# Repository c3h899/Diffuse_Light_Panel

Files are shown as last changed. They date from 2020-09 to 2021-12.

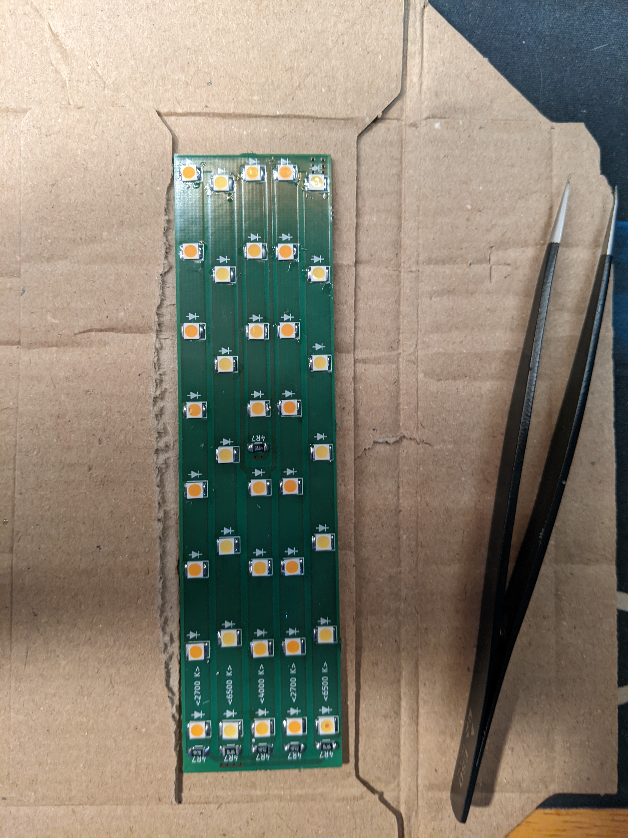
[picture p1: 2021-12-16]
Tri-Color LED/Preview/Proto-Module [Assembled].jpg

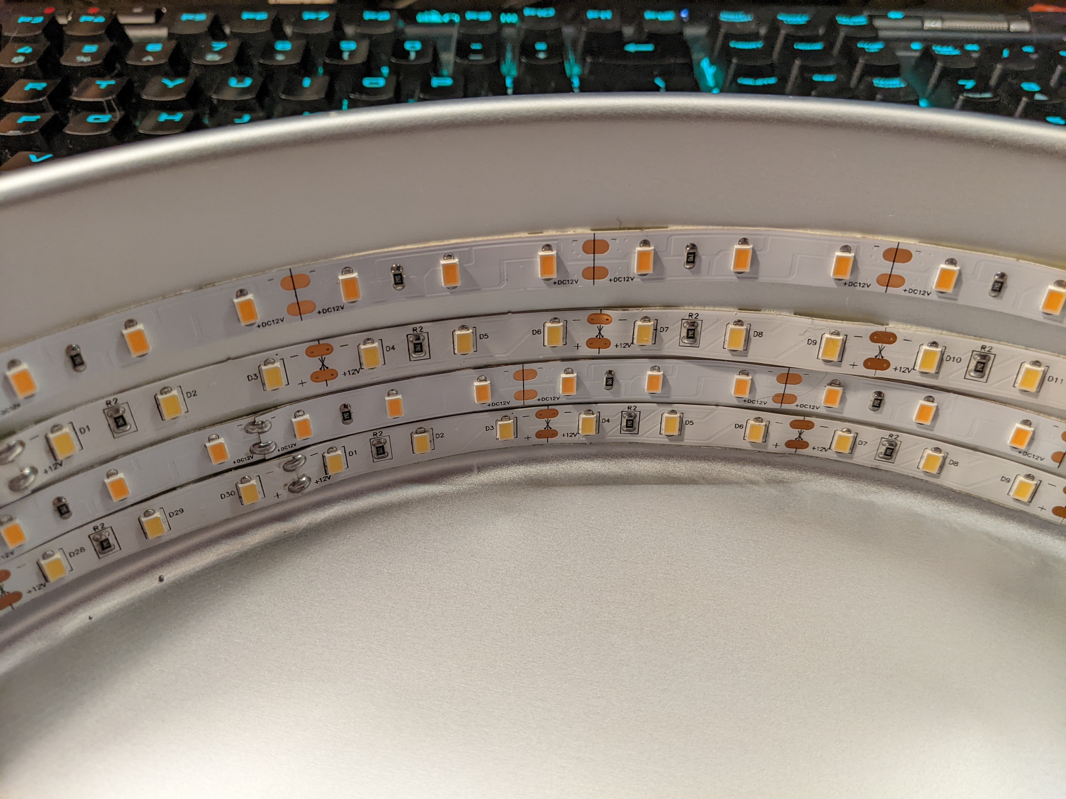
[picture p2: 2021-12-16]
Photos/Revision3_Interrior.jpg

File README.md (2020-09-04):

# Diffuse_Light_Panel
 - This is a derivative work. See LICENSE.

## Principle Design
 - Design is a direct variation on '$40 DIY Cake pan light'. See LICENSE.
 - Rim the interior of a metallic container with 5-ft lengths of LED strip lights.
 - Use two LED strips: 1) warm color temperature, 2) cool color temperature.
 - Use 2-channels of dimming to allow for variable color temperature.
 - Cover the aperture with 2 layers of diffusion material.
 - Result will consume 10-ft total length of LED strip lighting.

## Future Revisions
 - Future implementations should consider these changes for an improved product.
 - Dimmers use 10k (Ohm) multi-turn potentiometer. Depopulate and replace.
 - An externally mounted pair of potentiometers would improve the quality of life.
 - Affix a standard barrel jack to power the lights rather than direct soldering.
 - Power button / switch (12 V, (4 to 6) A minimum rating). 

## Revision 3
 - Built revision 2 in a aluminum, 12-inch circular cake pan.
 - Absence of sharp corners improved ease of applying the LED strips.
 - Recessing the LED strips as deeply as possible is encouraged.
 - Recessing the strips improves lighting uniformity (as one should expect).

## Revision 2
 - Applied 2 layers of the specified diffusion material.
 - SUBSTANTIAL improvement of lighting uniformity. Highly recommended.

## Revision 1
 - Moved to a switch-mode (more-or-less) constant current dimmer.
 - Dimmer requires many turns required before noticeable dimming.
 - Screw terminals on dimmer ineffective. Soldered wires directly to pads.
 - Scan-line artifacts resolved / not noticeable.
 - Moved to a cardboard box lined with printer paper: Acceptable.

## Revision 0
 - Non-Stick bread pan used as container. Aperture: acceptable, AVOID NON-STICK CONTAINERS.
 - (Cheap) PWM Dimmer was used, renders the light incompatible with videography.
 - Scan-line artifacts emerge from the interaction of the PWM and the image sensor.
 - Without dimmer, 2 strips of LEDs draw a (combined) (4 to 5) A at 12 V, (50 to 60) W.
 - At full power, these LEDs get HOT. Intended brightness achieved near 1 A combined.

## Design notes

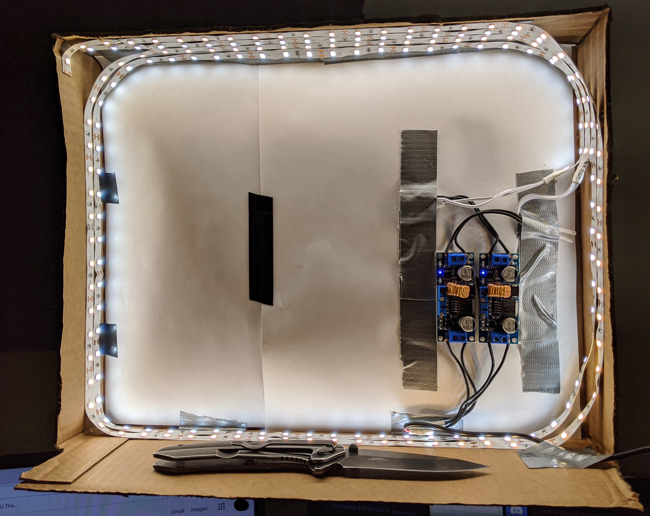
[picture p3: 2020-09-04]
Photos/Revision2_UnEnclosed.jpg

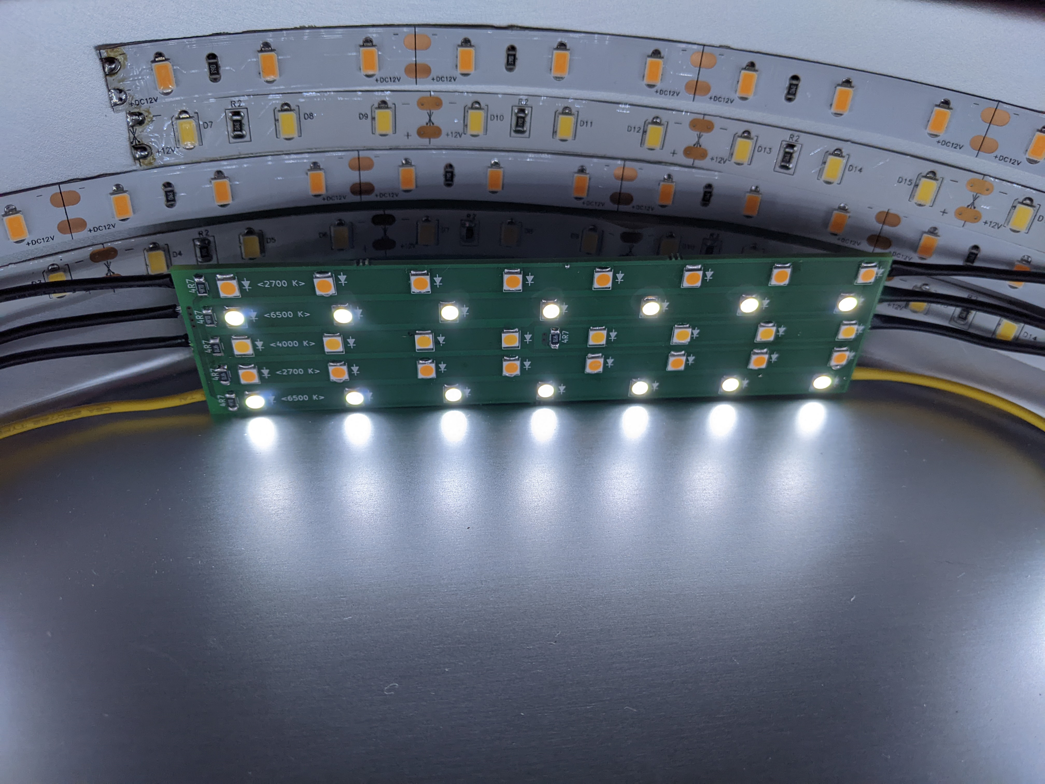
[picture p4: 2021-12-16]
Tri-Color LED/Preview/Side by Side.jpg

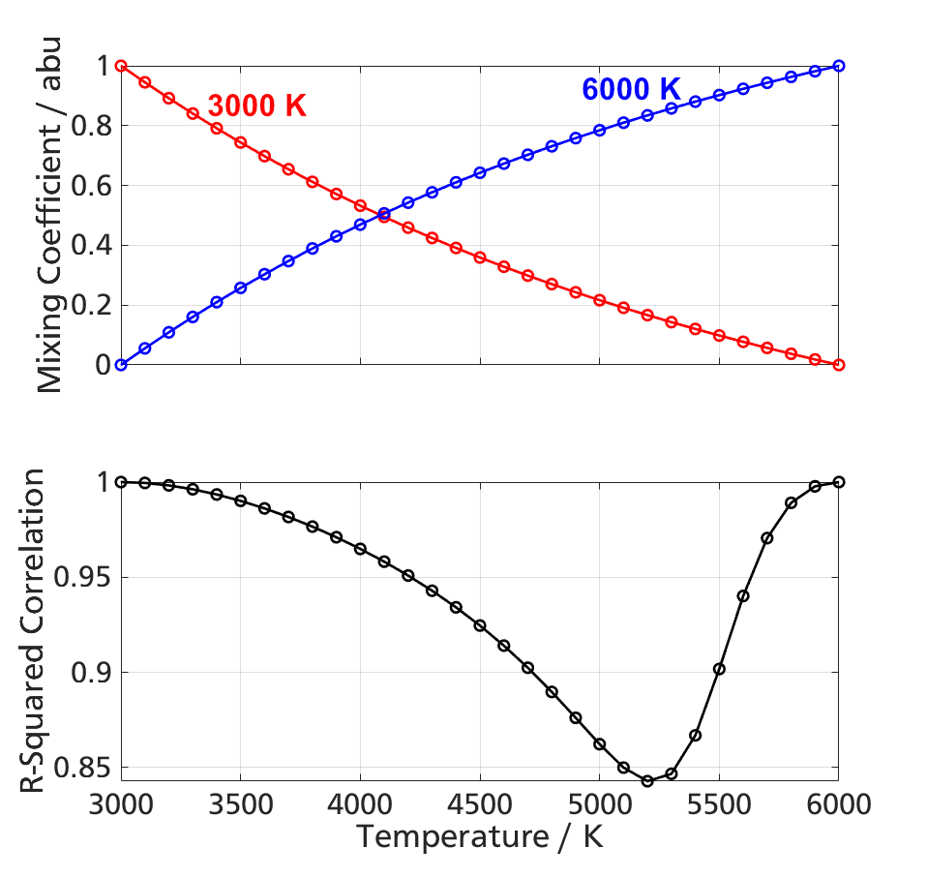
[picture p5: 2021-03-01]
Ideal_Model/3000-6000 Mixing.png

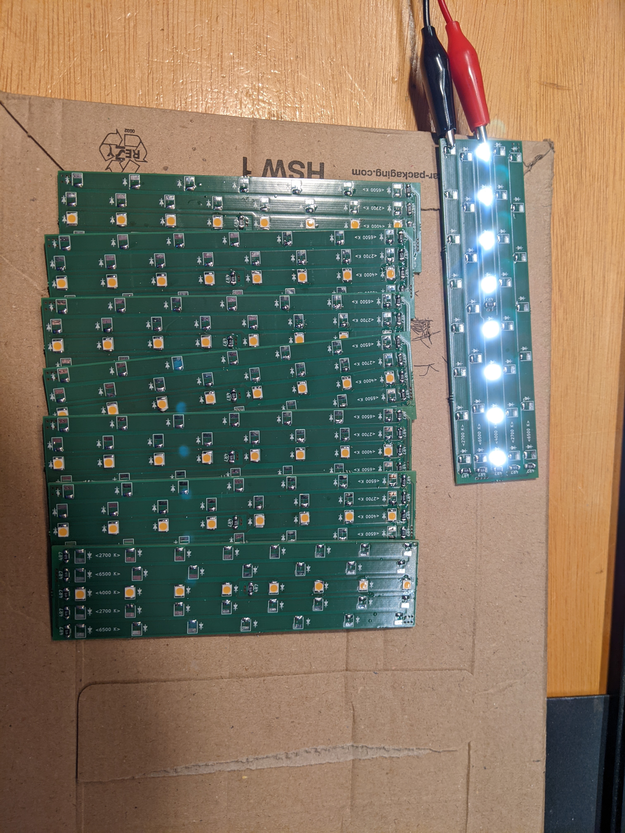
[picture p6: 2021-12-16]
Tri-Color LED/Preview/Proto-Modules.jpg

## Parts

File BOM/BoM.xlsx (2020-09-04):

Count | Name | Unit Cost | Total Cost
1 | MARSWELL CRI 90+ LED Strip Lights Pure White SMD5630 (https://www.amazon.com/gp/product/B01NAXYEBE) | 25.99 | 25.99
1 | MARSWELL CRI 90+ LED Strip Lights Warm White SMD5630 (https://www.amazon.com/gp/product/B01NAXYEBE) | 25.99 | 25.99
3 | HitLights 60 Watt LED Power Adapter […] 5 Amps, 110V AC - 12V DC (https://www.amazon.com/gp/product/B00HENQAMS) | 17.99 | 53.97
3 | Wilton Round Cake Pan, 3 inch x 12 inch (https://www.amazon.com/Wilton-Aluminum-Round-Cake-3-Inch/dp/B00004S7YP) | 13.92 | 41.76
6 | DZS Elec DC-DC Step-down [CC] […] 4-38v Input to 1.25-36v […] 5A 75W Converter (https://www.amazon.com/gp/product/B06XT6KMPX) | 8.99 | 53.94
1 | Neewer 2 Yard x 60 Inch/1.8M x 1.5M Nylon Silk White Seamless Diffusion (https://www.amazon.com/Neewer-Seamless-Diffusion-Photography-Lighting/dp/B019GSCL5S) | 20.99 | 20.99
Sub-Total |  |  | 222.64
Amortized Cost / Unit |  |  | 74.21333333

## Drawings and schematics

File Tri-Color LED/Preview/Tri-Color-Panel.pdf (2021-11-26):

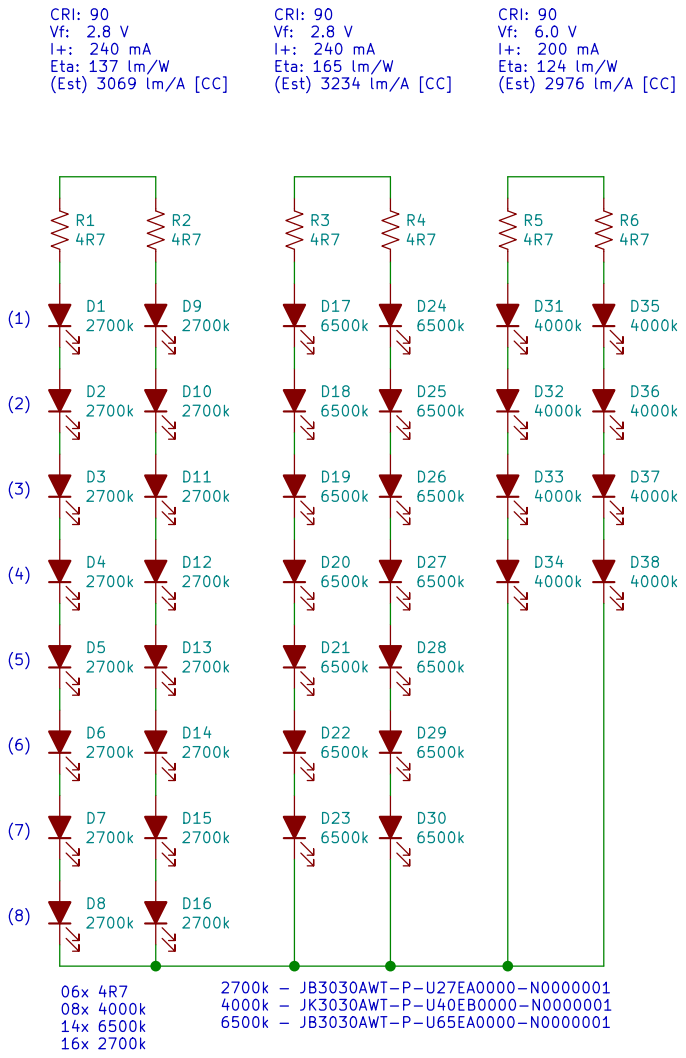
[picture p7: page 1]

(Est) 2976 lm/A [CC] CRI: 90 Vf: 2.8 V

Id: 1/1 Title: File: Tri-Color-Panel.sch Sheet: /

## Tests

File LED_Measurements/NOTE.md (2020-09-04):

#Note
Measurements made based on supply readout on a linear bench supply operating in constant current mode. Measurements were made with progressively increasing supply current and no external heat-sinking for the LEDs. They seem to have a substantial thermal coefficient, re-measuring at a lesser current after allowing the LEDs to be heated by substantially greater supply currents produced appreciable deviations from the included measurements.

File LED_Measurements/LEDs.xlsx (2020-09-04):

PSU | Blue | 31 |  | Red | 32
I_PSU | V_PSU | I_Blue | V_Diode | V | I_Red | V_Diode
0.01 | 7.62 | 0.0003225806452 | 2.535806452 | 7.57 | 0.0003125 | 2.5359375
0.02 | 7.71 | 0.0006451612903 | 2.561612903 | 7.65 | 0.000625 | 2.561875
0.03 | 7.77 | 0.0009677419355 | 2.577419355 | 7.71 | 0.0009375 | 2.5778125
0.04 | 7.81 | 0.001290322581 | 2.58655914 | 7.75 | 0.00125 | 2.587083333
0.05 | 7.85 | 0.001612903226 | 2.595698925 | 7.79 | 0.0015625 | 2.596354167
0.06 | 7.89 | 0.001935483871 | 2.60483871 | 7.83 | 0.001875 | 2.605625
0.07 | 7.92 | 0.002258064516 | 2.610645161 | 7.86 | 0.0021875 | 2.6115625
0.08 | 7.95 | 0.002580645161 | 2.616451613 | 7.89 | 0.0025 | 2.6175
0.09 | 7.98 | 0.002903225806 | 2.622258065 | 7.91 | 0.0028125 | 2.6234375
0.1 | 8.01 | 0.003225806452 | 2.628064516 | 7.94 | 0.003125 | 2.629375
0.12 | 8.05 | 0.003870967742 | 2.633010753 | 8 | 0.00375 | 2.634583333
0.14 | 8.1 | 0.004516129032 | 2.641290323 | 8.04 | 0.004375 | 2.643125
0.16 | 8.15 | 0.005161290323 | 2.649569892 | 8.09 | 0.005 | 2.651666667
0.18 | 8.2 | 0.005806451613 | 2.657849462 | 8.14 | 0.005625 | 2.660208333
0.2 | 8.25 | 0.006451612903 | 2.666129032 | 8.19 | 0.00625 | 2.66875
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

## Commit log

2020-09-04 Initial commit.
    [BoM.xlsx, LEDs.xlsx]
2020-09-04 Update README.md
    title case.
2021-11-26 Testing Prototype
    3 Colors, Discrete Parts + Solid PCB's
    [Tri-Color-Panel-B_Cu.gbr, Tri-Color-Panel-B_Mask.gbr, Tri-Color-Panel-B_Paste.gbr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]
2021-12-14 Updated LED to CREE Footprint
    Previous footprint is passable; Soldering is inconvenient.
    [Tri-Color-Panel-B_Cu.gbr, Tri-Color-Panel-B_Mask.gbr, Tri-Color-Panel-B_Paste.gbr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]
